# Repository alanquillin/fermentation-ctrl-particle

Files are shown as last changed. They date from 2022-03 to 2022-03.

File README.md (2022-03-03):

# fermentation-controller

A Particle project named fermentation-controller

## Welcome to your project!

Every new Particle project is composed of 3 important elements that you'll see have been created in your project directory for fermentation-controller.

#### ```/src``` folder:  
This is the source folder that contains the firmware files for your project. It should *not* be renamed. 
Anything that is in this folder when you compile your project will be sent to our compile service and compiled into a firmware binary for the Particle device that you have targeted.

If your application contains multiple files, they should all be included in the `src` folder. If your firmware depends on Particle libraries, those dependencies are specified in the `project.properties` file referenced below.

#### ```.ino``` file:
This file is the firmware that will run as the primary application on your Particle device. It contains a `setup()` and `loop()` function, and can be written in Wiring or C/C++. For more information about using the Particle firmware API to create firmware for your Particle device, refer to the [Firmware Reference](https://docs.particle.io/reference/firmware/) section of the Particle documentation.

#### ```project.properties``` file:  
This is the file that specifies the name and version number of the libraries that your project depends on. Dependencies are added automatically to your `project.properties` file when you add a library to a project using the `particle library add` command in the CLI or add a library in the Desktop IDE.

## Adding additional files to your project

#### Projects with multiple sources
If you would like add additional files to your application, they should be added to the `/src` folder. All files in the `/src` folder will be sent to the Particle Cloud to produce a compiled binary.

#### Projects with external libraries
If your project includes a library that has not been registered in the Particle libraries system, you should create a new folder named `/lib/<libraryname>/src` under `/<project dir>` and add the `.h`, `.cpp` & `library.properties` files for your library there. Read the [Firmware Libraries guide](https://docs.particle.io/guide/tools-and-features/libraries/) for more details on how to develop libraries. Note that all contents of the `/lib` folder and subfolders will also be sent to the Cloud for compilation.

## Compiling your project

When you're ready to compile your project, make sure you have the correct Particle device target selected and run `particle compile <platform>` in the CLI or click the Compile button in the Desktop IDE. The following files in your project folder will be sent to the compile service:

- Everything in the `/src` folder, including your `.ino` application file
- The `project.properties` file for your project
- Any libraries stored under `lib/<libraryname>/src`

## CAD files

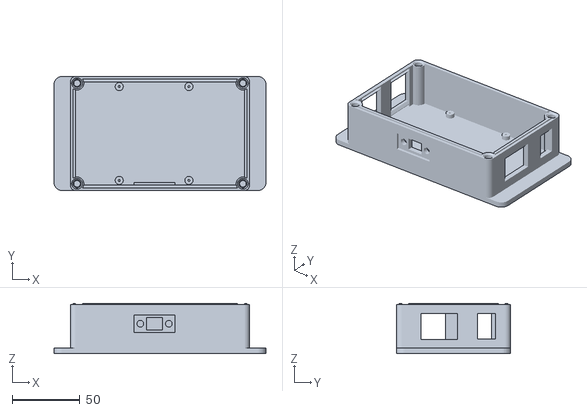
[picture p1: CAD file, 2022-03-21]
drawings/case/case-bottom (Meshed).stl
156.0 x 84.0 x 37.0

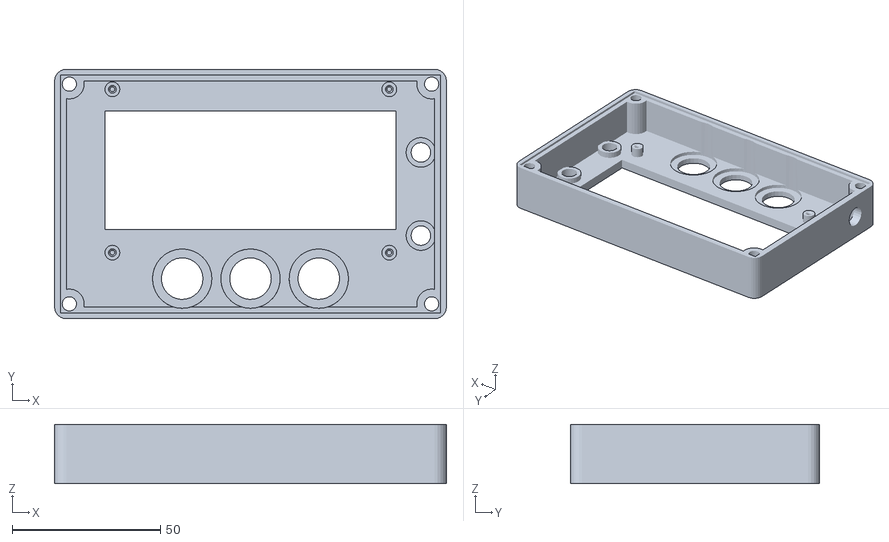
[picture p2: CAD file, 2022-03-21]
drawings/case/case-top (Meshed).stl
132.0 x 84.0 x 20.0

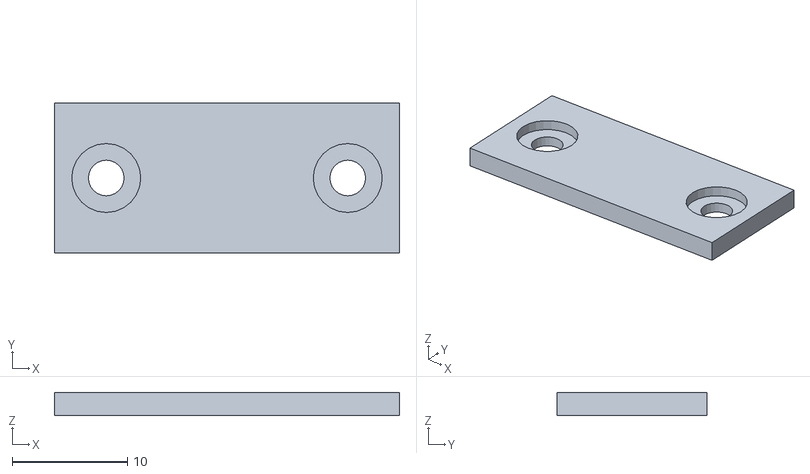
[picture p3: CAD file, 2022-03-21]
drawings/case/case-botton-usb-cover (Meshed).stl
30.0 x 13.0 x 2.00

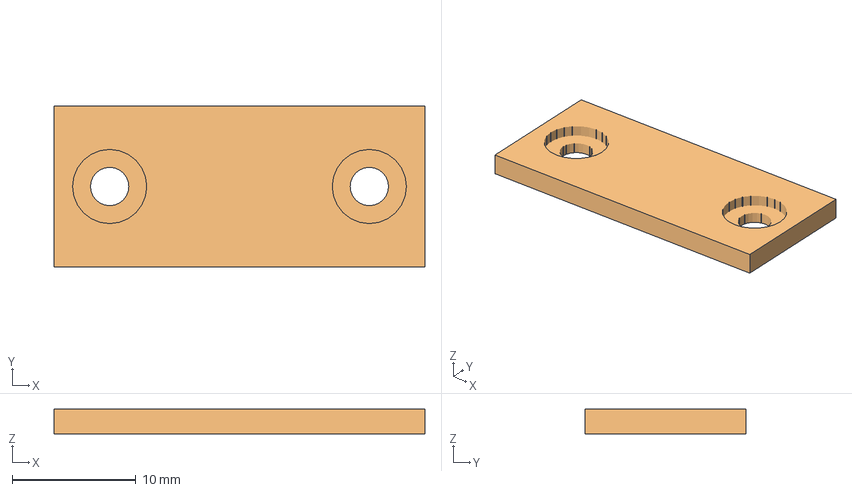
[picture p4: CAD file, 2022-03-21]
drawings/case/case-botton-usb-cover.FCStd
30.0 x 13.0 x 2.00 mm
Cut001 (Meshed)

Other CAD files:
drawings/case/case-bottom.FCStd
drawings/case/case-top.FCStd

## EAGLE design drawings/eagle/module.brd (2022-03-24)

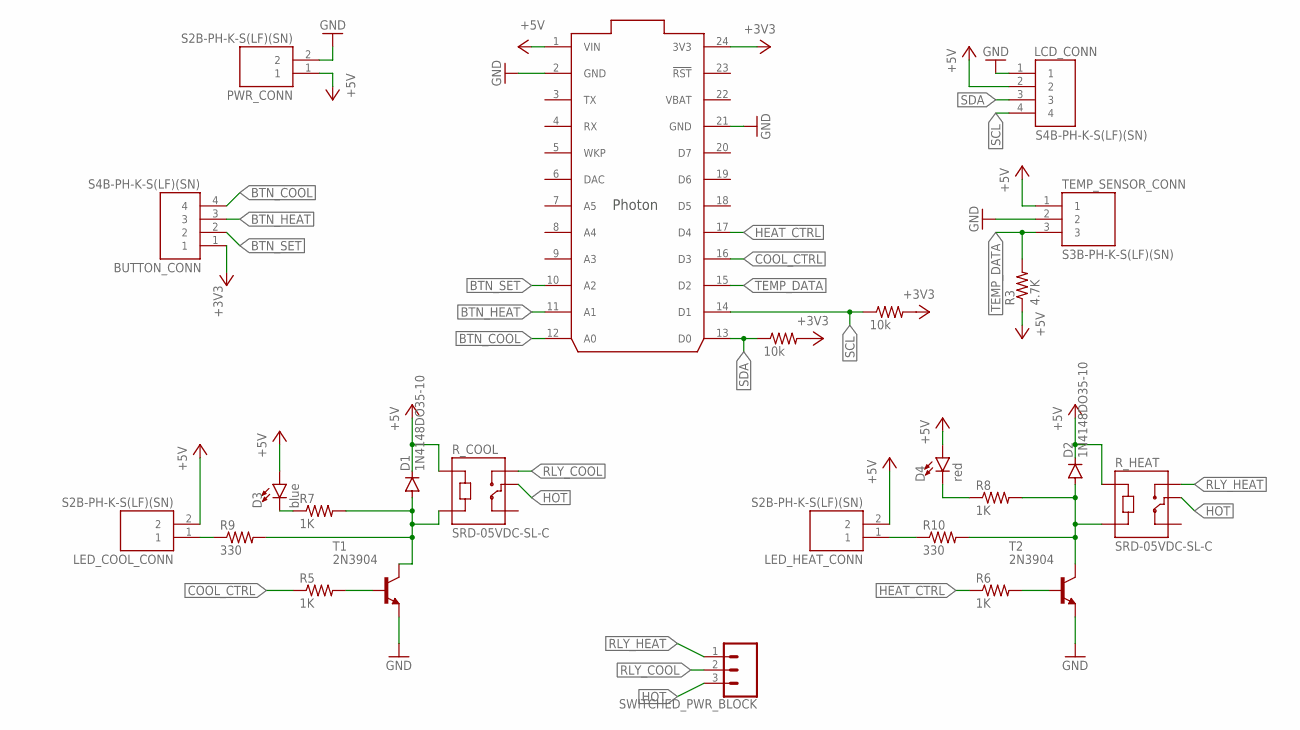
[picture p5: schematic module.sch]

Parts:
BUTTON_CONN: S4B-PH-K-S(LF)(SN); JST_S4B-PH-K-S(LF)(SN); MPN S4B-PH-K-S (LF)(SN)
D1, D2: 1N4148DO35-10; DO35-10; MPN 1N4148 (DO-35)
D3: blue; LED_3MM; MPN TLHB4400
D4: red; LED_3MM; MPN 4300F1LC
LCD_CONN: S4B-PH-K-S(LF)(SN); JST_S4B-PH-K-S(LF)(SN); MPN S4B-PH-K-S (LF)(SN)
LED_COOL_CONN: S2B-PH-K-S(LF)(SN); JST_S2B-PH-K-S(LF)(SN); MPN S2B-PH-K-S (LF)(SN)
LED_HEAT_CONN: S2B-PH-K-S(LF)(SN); JST_S2B-PH-K-S(LF)(SN); MPN S2B-PH-K-S (LF)(SN)
PWR_CONN: S2B-PH-K-S(LF)(SN); JST_S2B-PH-K-S(LF)(SN); MPN S2B-PH-K-S (LF)(SN)
R1, R2: 10k; 0207/10
R3: 4.7K; 0207/10
R5, R6, R7, R8: 1K; 0207/10
R9, R10: 330; 0207/10
R_COOL: SRD-05VDC-SL-C; RELAY_SRD-05VDC-SL-C
R_HEAT: SRD-05VDC-SL-C; RELAY_SRD-05VDC-SL-C
SWITCHED_PWR_BLOCK: CONN_03-SCREW-5MM; SCREWTERMINAL-5MM-3
T1, T2: 2N3904; TO92; MPN 2N3904TF
TEMP_SENSOR_CONN: S3B-PH-K-S(LF)(SN); JST_S3B-PH-K-S(LF)(SN); MPN S3B-PH-K-S (LF)(SN)
U$1: PHOTON_WITH_HEADERS; PHOTON; MPN PHOTONH

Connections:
+3V3: BUTTON_CONN.1, R1.2, R2.2, U$1.24 (3V3)
+5V: D1.C, D2.C, D3.A, D4.A, LCD_CONN.2, LED_COOL_CONN.2, LED_HEAT_CONN.2, PWR_CONN.1, R3.1, R_COOL.A1, R_HEAT.A1, TEMP_SENSOR_CONN.1, U$1.1 (VIN)
BTN_COOL: BUTTON_CONN.4, U$1.12 (A0)
BTN_HEAT: BUTTON_CONN.3, U$1.11 (A1)
BTN_SET: BUTTON_CONN.2, U$1.10 (A2)
COOL_CTRL: R5.1, U$1.16 (D3)
GND: LCD_CONN.1, PWR_CONN.2, T1.3 (E), T2.3 (E), TEMP_SENSOR_CONN.2, U$1.2 (GND), U$1.21 (GND)
HEAT_CTRL: R6.1, U$1.17 (D4)
HOT: R_COOL.COM, R_HEAT.COM, SWITCHED_PWR_BLOCK.3
unnamed: LED_COOL_CONN.1, R9.1
unnamed: LED_HEAT_CONN.1, R10.1
unnamed: D1.A, R7.2, R9.2, R_COOL.A2, T1.1 (C)
unnamed: D3.K (C), R7.1
unnamed: R5.2, T1.2 (B)
unnamed: R6.2, T2.2 (B)
unnamed: D2.A, R8.2, R10.2, R_HEAT.A2, T2.1 (C)
unnamed: D4.K (C), R8.1
RLY_COOL: R_COOL.NO, SWITCHED_PWR_BLOCK.2
RLY_HEAT: R_HEAT.NO, SWITCHED_PWR_BLOCK.1
SCL: LCD_CONN.4, R1.1, U$1.14 (D1)
SDA: LCD_CONN.3, R2.1, U$1.13 (D0)
TEMP_DATA: R3.2, TEMP_SENSOR_CONN.3, U$1.15 (D2)
VBAT: U$1.22 (VBAT)

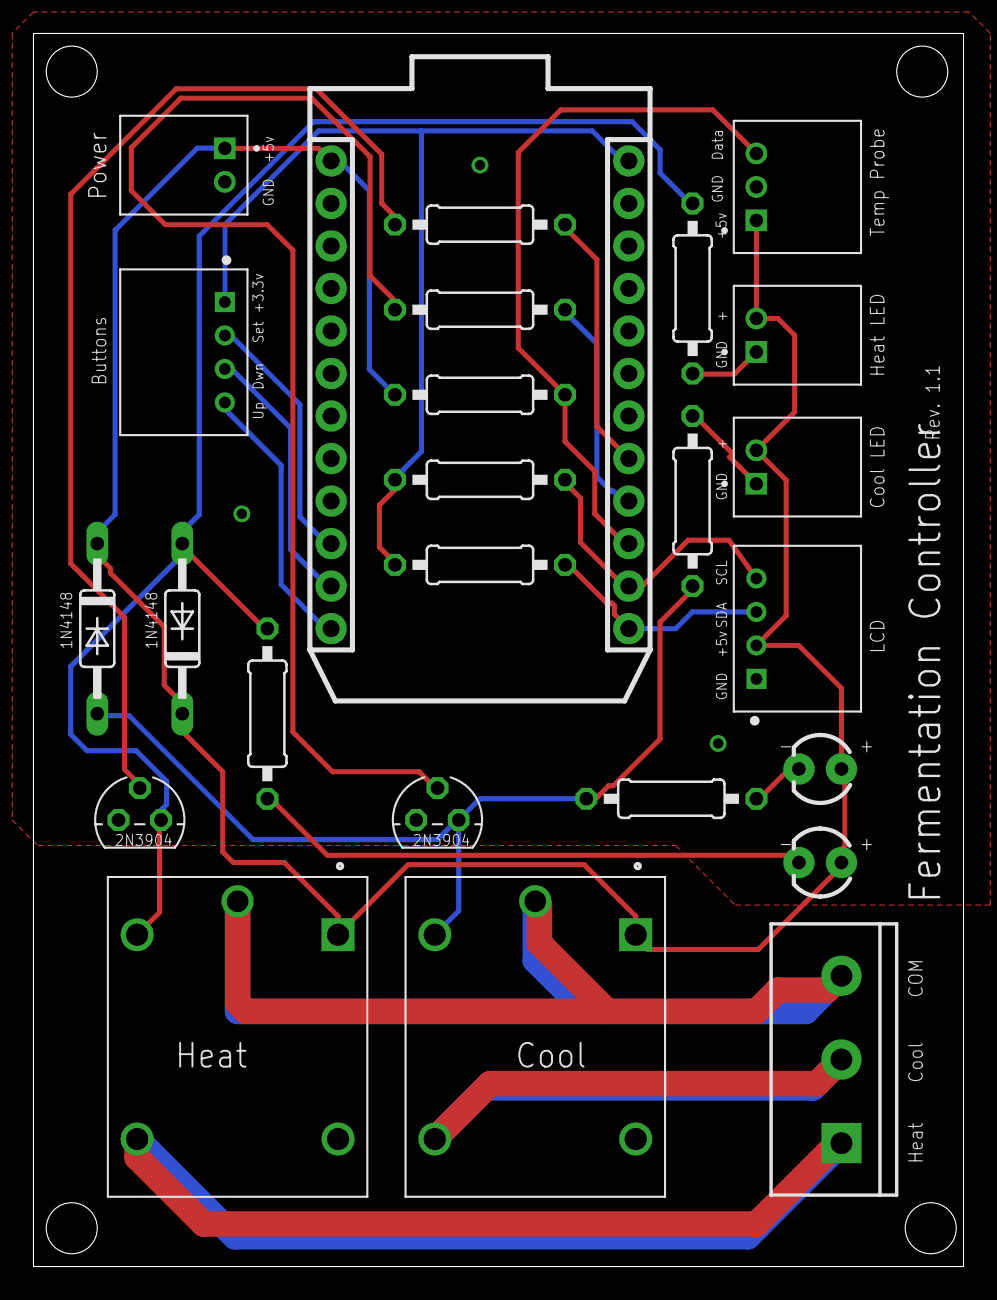
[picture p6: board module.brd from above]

Board: 2 copper layers, 55.5 x 73.7 mm, 25 parts (0 on the bottom side), 22 nets.

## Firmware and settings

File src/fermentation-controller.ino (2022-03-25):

SYSTEM_THREAD(ENABLED);

/*
 * Project fermentation-controller
 * Description:
 * Author: Alan Quillin
 */

#include "constants.h"
#include "diagnostics.h"
#include "service.h"
#include <LiquidCrystal_I2C_Spark.h>
#include <DS18B20.h>
#include <math.h>
#include <CircularBuffer.h>

const LogLevel APP_LOG_LEVEL = LOG_LEVEL_ALL;
SerialLogHandler logHandler(LOG_LEVEL_WARN, { // Logging level for non-application messages
    { "app", APP_LOG_LEVEL }, // Logging level for application messages
    { "app.service", LOG_LEVEL_ALL }
});

//func prototypes
void refreshDisplay(bool clear=false);

// modes
const uint8_t MODE_OFF         = 0;
const uint8_t MODE_COOLING     = 1;
const uint8_t MODE_HEATING     = 2;
const uint8_t MODE_HOLD        = 3;
const uint8_t MODE_DIAGNOSTICS = 10;

// states
const uint8_t STATE_DEFAULT            = 0;
const uint8_t STATE_MENU               = 1;
const uint8_t STATE_MENU_SET_TEMP      = 2;
const uint8_t STATE_MENU_CALIBRATE     = 3;
const uint8_t STATE_MENU_SET_PRECISION = 4;
const uint8_t STATE_MENU_HEAT_DIFF     = 5;
const uint8_t STATE_MENU_COOL_DIFF     = 6;
const uint8_t STATE_MENU_RESET_CONFIG  = 7;

// other constants
const uint8_t MAXRETRY = 4;
const uint16_t LONG_BTN_PRESS_MILS = 2000;
const uint16_t STATS_PUSH_FREQUENCY_MS = 5000;

// dataservice
const String HOST = "<__IP_Address__>";
const uint16_t PORT = 80;

CircularBuffer<device_stats_t,100> stats;

LiquidCrystal_I2C lcd(0x27, 20, 4);
DS18B20 ds18b20(P_DS_DATA, true);

DataService dataService(HOST, PORT);
bool serviceReady = false;
uint32_t serviceFailCnt = 0;
uint32_t lastServiceCheck;
uint32_t lastStatsPush;
String manufacturerId;
String deviceId;
byte mac[6];

struct Config {
  double targetTemp;
  double coolingDifferential;
  double heatingDifferential;
  double tempPrecision;
  double calibrationDiff;
  bool programOn;
};
Config config = {68, 1, 1, .5, 0, true};

double fahrenheit = 0;
double prevFahrenheit = fahrenheit;
double tTargetTemp = config.targetTemp;
double tCoolingDifferential = config.coolingDifferential;
double tHeatingDifferential = config.heatingDifferential;
double tTempPrecision = config.tempPrecision;
double calibrationTemp;
int currentMode = MODE_HOLD;
int displayState = STATE_DEFAULT;
bool refreshLock = false;
uint32_t msLastSample;
long latestMenuActivityTS;

// menu state vars
const String MENU_SET_MODE_OPTION = "<SET MODE>";
const uint8_t MENU_ITEM_SIZE = 9;
const String MENU_ITEMS[MENU_ITEM_SIZE] = {
  "Set Target Temp   ",
  MENU_SET_MODE_OPTION,
  "Calibrate Temp    ",
  "Set Heating Diff  ",
  "Set Cooling Diff  ",
  "Set Temp Precision",
  "Reset Config      ",
  "Run Diagnostics   ",
  "Back              "
};
int menuFirstItemIndex = 0;
int menuItemIndex = 0;

// button state vars
int btnUpState = LOW;
uint32_t btnUpPressStart = 0;
bool btnUpLongPressedHandled = false;
int btnDownState = LOW;
uint32_t btnDownPressStart = 0;
bool btnDownLongPressedHandled = false;
int btnSetState = LOW;
uint32_t btnSetPressStart = 0;
bool btnSetLongPressedHandled = false;

// Timers
Timer tempTimer(2000, getTemp);
Timer refreshDisplayTimer(1000, refreshDisplayWrapper);
Timer setModeTimer(1000, setModeCtl);
Timer menuInactivityTimer(2000, checkMenuInactivity);

Diagnostics diag(lcd, ds18b20, dataService, diagnosticsComplete, diagnosticsCancelled);

// setup() runs once, when the device is first turned on.
void setup() {
  // Put initialization like pinMode and begin functions here.
  Serial.begin(9600);
  
  Log.info("Initializing...");
  Log.trace("Initializing pins...");
  pinMode(P_BTN_UP, INPUT_PULLDOWN);
  pinMode(P_BTN_DOWN, INPUT_PULLDOWN);
  pinMode(P_BTN_SET, INPUT_PULLDOWN);

  pinMode(P_CTRL_COOL, OUTPUT);
  pinMode(P_CTRL_HEAT, OUTPUT);

  for(uint i=0; i < arraySize(EXTRA_GND); i++) {
    pinMode(EXTRA_GND[i], OUTPUT);
    digitalWrite(EXTRA_GND[i], LOW);
  }

  for(uint i=0; i < arraySize(EXTRA_PWR); i++) {
    pinMode(EXTRA_PWR[i], OUTPUT);
    digitalWrite(EXTRA_PWR[i], HIGH);
  }

  Log.trace("Pins initialization done.");

  Log.info("Starting up...");
  lcd.init();
  lcd.backlight();
  lcd.clear();
  lcd.print("Initializing... ");
  
  manufacturerId = System.deviceID();

  Log.trace("Device Manufacturer Id: %s", manufacturerId.c_str());
  WiFi.macAddress(mac);
  Log.trace("Wifi MAC address: %02x:%02x:%02x:%02x:%02x:%02x", mac[0], mac[1], mac[2], mac[3], mac[4], mac[5]);
  Log.trace("Wifi IP address: %s", WiFi.localIP().toString().c_str());

  lcd.setCursor(0,1);
  lcd.print("WiFi... ");
  waitFor(WiFi.ready, 30000);
  lcd.printf("%s", WiFi.ready() ? "connected!" : "timeedout");

  lcd.setCursor(0,2);
  lcd.print("Loading config... ");
  Log.trace("Setting up cloud functions and variables.");
  Particle.function("setTargetTempF", cldSetTargetTemp);
  Particle.function("setMode", cldSetMode);

  Particle.variable("currentTemperature", fahrenheit);
  Particle.variable("tempPrecision", config.tempPrecision);
  Particle.variable("targetTemperature", config.targetTemp);
  Particle.variable("calibrationDifferential", config.calibrationDiff);
  Log.trace("Cloud stuff all set up!");
  
  loadConfig();
  lcd.print("ok");

  lcd.setCursor(0,3);
  lcd.print("Data Svc... ");
  uint8_t pingStatus = ping();
  switch(pingStatus) {
    case 0:
      lcd.print("success!");
      break;
    case 1:
      lcd.print("failed");
      break;
    case 2:
      lcd.print("error");
      break;
  }

  Log.trace("Device Id: %s", deviceId.c_str());
  Log.trace("Target Temp: %.2f", config.targetTemp);
  Log.trace("Target Temp Precision: %.2f", config.tempPrecision);
  Log.trace("Calibration Differential: %.2f", config.calibrationDiff);
  Log.trace("Heating Differential: %.2f", config.heatingDifferential);
  Log.trace("Cooling Differential: %.2f", config.coolingDifferential);
  Log.trace("Program on: %s", config.programOn ? "true" : "false");
  Log.trace("Temp sensor chip type: %x", ds18b20.getChipType());
  Log.trace("Temp sensor chip name: %s", ds18b20.getChipName());

  tempTimer.start();
  refreshDisplayTimer.start();
  setModeTimer.start();

  Log.info("Initialization complete!");
  lcd.setCursor(16,0);
  lcd.print("done");

  delay(2);
  setMode(config.programOn ? MODE_HOLD : MODE_OFF);
  setState(STATE_DEFAULT);
}

// loop() runs over and over again, as quickly as it can execute.
void loop() {
  bool isBtnPresseed = false;
  int _btnUpState = digitalRead(P_BTN_UP);
  uint32_t now = millis();
  if (_btnUpState != btnUpState) {
    if(btnUpState == HIGH) {
      upBtnPressed();
    } else {
      isBtnPresseed = true;
      btnUpLongPressedHandled = false;
      btnUpPressStart = millis();
    }
    btnUpState = _btnUpState;
  } else if (btnUpState == HIGH) {
    isBtnPresseed = true;
    if ((now - btnUpPressStart) >= LONG_BTN_PRESS_MILS && !btnUpLongPressedHandled) {
      upBtnPressedLong();
    }
  }

  int _btnDownState = digitalRead(P_BTN_DOWN);
  if (_btnDownState != btnDownState) {
    if(btnDownState == HIGH) {
      downBtnPressed();
    } else {
      isBtnPresseed = true;
      btnDownLongPressedHandled = false;
      btnDownPressStart = millis();
    }
    btnDownState = _btnDownState;
  } else if (btnDownState == HIGH) {
    isBtnPresseed = true;
    
    if ((now - btnDownPressStart) >= LONG_BTN_PRESS_MILS && !btnDownLongPressedHandled) {
      downBtnPressedLong();
    }
  }

  int _btnSetState = digitalRead(P_BTN_SET);
  if (_btnSetState != btnSetState) {
    if(btnSetState == HIGH) {
      setBtnPressed();
    } else {
      isBtnPresseed = true;
      btnSetLongPressedHandled = false;
      btnSetPressStart = millis();
    }
    btnSetState = _btnSetState;
  } else if (btnSetState == HIGH) {
    isBtnPresseed = true;
    if ((now - btnSetPressStart) >= LONG_BTN_PRESS_MILS && !btnSetLongPressedHandled) {
      setBtnPressedLong();
    }
  }

  if (currentMode == MODE_DIAGNOSTICS) {
    return;
  }

  if (prevFahrenheit != fahrenheit) {
    if(prevFahrenheit != NAN && prevFahrenheit > 0 && prevFahrenheit < 100 && fahrenheit != NAN && fahrenheit > 0 && fahrenheit < 100) {
      float diff = prevFahrenheit - fahrenheit;
      Log.trace("getTemp: _prev: %f, diff: %f", prevFahrenheit, diff);
      if (diff <= -0.02 || diff >= 0.02) {
        Log.trace("getTemp: Temp has changed (after rounding).  Old: %f, New: %f, diff: %f.  Updating database.", prevFahrenheit, fahrenheit, diff);
        prevFahrenheit = fahrenheit;
        stats.push({fahrenheit, Time.now()}); // put stat record to the end of the queue
      }
    } 
  }

  if (!isBtnPresseed && displayState == STATE_DEFAULT) {
    // uint16_t nextCheckFreq = serviceReady ? 10000 : serviceFailCnt > 20 ? 20000 : (serviceFailCnt * 1000);
    // uint32_t elapsed = (now - lastServiceCheck);
    // if (elapsed >= nextCheckFreq) {
    //   Log.trace("%.1f seconds have elapsed since the last service check...", (float(elapsed) / 1000));
    //   Log.info("Pinging service");
    //   ping();
    // }
    // if (serviceReady && (lastStatsPush == 0 || (now - lastStatsPush > STATS_PUSH_FREQUENCY_MS))) {
    //   pushStats();
    // }
  }
}

void setState(int nextState) {
  int _prevDisplayState = displayState;
  
  if (_prevDisplayState == STATE_DEFAULT) {
    refreshDisplayTimer.stop();
  }

  displayState = nextState;
  switch(nextState) {
    case STATE_DEFAULT:
      menuInactivityTimer.stop();
      refreshDisplayTimer.start();
      break;
    case STATE_MENU:
      latestMenuActivityTS = Time.now();
      menuInactivityTimer.start();
      if (_prevDisplayState == STATE_DEFAULT) {
        menuFirstItemIndex = 0;
        menuItemIndex = 0;
      }
      break;
    case STATE_MENU_SET_TEMP:
      tTargetTemp = config.targetTemp;
      break;
    case STATE_MENU_CALIBRATE:
      calibrationTemp = ((isnan(fahrenheit) || fahrenheit <= 0) ? config.targetTemp : fahrenheit) + config.calibrationDiff;
      break;
    case STATE_MENU_HEAT_DIFF:
      tHeatingDifferential = config.heatingDifferential;
      break;
    case STATE_MENU_COOL_DIFF:
      tCoolingDifferential = config.coolingDifferential;
      break;
    case STATE_MENU_SET_PRECISION:
      tTempPrecision = config.tempPrecision;
      break;
  }
  refreshDisplay(true);
}

void upBtnPressed() {
  if (currentMode == MODE_DIAGNOSTICS) {
    diag.upBtnPressed();
    return;
  }
  
  uint32_t now = millis();
  if ((now - btnUpPressStart) >= LONG_BTN_PRESS_MILS) {
    Log.trace("up pressed function ignored since the button is long pressed");
    return;
  }
  Log.trace("Up btn pressed");
  
  if (displayState != STATE_DEFAULT) {
    latestMenuActivityTS = Time.now();
  }

  switch(displayState) {
    case STATE_MENU_SET_TEMP:
      tTargetTemp = tTargetTemp + config.tempPrecision;
      refreshDisplay();
      break;
    case STATE_MENU:
      if (menuItemIndex == 0) {
        menuItemIndex = (MENU_ITEM_SIZE - 1);
        menuFirstItemIndex = menuItemIndex - 2;
      } else {
        menuItemIndex = menuItemIndex - 1;
        if(menuFirstItemIndex > menuItemIndex) {
          menuFirstItemIndex = menuItemIndex;
        }
      }
      refreshDisplay();
      break;
    case STATE_MENU_CALIBRATE:
      calibrationTemp = calibrationTemp + .1;
      refreshDisplay();
      break;
    case STATE_MENU_SET_PRECISION:
      tTempPrecision = tTempPrecision + .1;
      refreshDisplay();
      break;
    case STATE_MENU_HEAT_DIFF:
      tHeatingDifferential = tHeatingDifferential + config.tempPrecision;
      refreshDisplay();
      break;
    case STATE_MENU_COOL_DIFF:
      tCoolingDifferential = tCoolingDifferential + config.tempPrecision;
      refreshDisplay();
      break;
    case STATE_MENU_RESET_CONFIG:
      config = {68, 1, 1, .5, 0, config.programOn};
      saveConfig();
      setState(STATE_MENU);
      break;
  }
}

void upBtnPressedLong() {
  btnUpLongPressedHandled = true;
}

void downBtnPressed() {
  if (currentMode == MODE_DIAGNOSTICS) {
    diag.downBtnPressed();
    return;
  }

  uint32_t now = millis();
  if ((now - btnDownPressStart) >= LONG_BTN_PRESS_MILS) {
    Log.trace("button pressed function ignored since the button is long pressed");
    return;
  }

  Log.trace("Down btn pressed");
  
  if (displayState != STATE_DEFAULT) {
    latestMenuActivityTS = Time.now();
  }

  switch(displayState) {
    case STATE_MENU_SET_TEMP:
      tTargetTemp = tTargetTemp - config.tempPrecision;
      refreshDisplay();
      break;
    case STATE_MENU:
      if (menuItemIndex == (MENU_ITEM_SIZE - 1)) {  
        menuItemIndex = 0;
        menuFirstItemIndex = 0;
      } else {
        menuItemIndex = menuItemIndex + 1;
        if ((menuItemIndex - menuFirstItemIndex) > 2) {
          menuFirstItemIndex = menuItemIndex - 2;
        }
      }
      refreshDisplay();
      break;
    case STATE_MENU_CALIBRATE:
      calibrationTemp = calibrationTemp - .1;
      refreshDisplay();
      break;
    case STATE_MENU_SET_PRECISION:
      if (tTempPrecision > .1) {
        tTempPrecision = tTempPrecision - .1;
        refreshDisplay();
      }
      break;
    case STATE_MENU_HEAT_DIFF:
      if(tHeatingDifferential > 0) {
        tHeatingDifferential = tHeatingDifferential - config.tempPrecision;
        if (tHeatingDifferential < 0) {
          tHeatingDifferential = 0;
        }
        refreshDisplay();
      }
      break;
    case STATE_MENU_COOL_DIFF:
      if(tCoolingDifferential > 0) {
        tCoolingDifferential = tCoolingDifferential - config.tempPrecision;
        if (tCoolingDifferential < 0) {
          tCoolingDifferential = 0;
        }
        refreshDisplay();
      }
      break;
    case STATE_MENU_RESET_CONFIG:
      setState(STATE_MENU);
      break;
  }
}

void downBtnPressedLong() {
  btnDownLongPressedHandled = true;
}

void setBtnPressed() {
  uint32_t now = millis();
  if ((now - btnSetPressStart) >= LONG_BTN_PRESS_MILS) {
    return;
  }

  if (currentMode == MODE_DIAGNOSTICS) {
    diag.setBtnPressed();
    return;
  }

  if (displayState != STATE_DEFAULT) {
    latestMenuActivityTS = Time.now();
  }

  switch(displayState) {
    case STATE_DEFAULT:
      setState(STATE_MENU_SET_TEMP);
      break;
    case STATE_MENU:
      switch(menuItemIndex) {
        case 0:
          setState(STATE_MENU_SET_TEMP);
          break;
        case 1:
          setMode(currentMode == MODE_OFF ? MODE_HOLD : MODE_OFF);
          config.programOn = currentMode != MODE_OFF;
          saveConfig();
          // TODO: Update data service
          // deviceService.updateProgramState(deviceId, config.programOn);
          setState(STATE_DEFAULT);
          break;
        case 2:
          calibrationTemp = fahrenheit;
          setState(STATE_MENU_CALIBRATE);
          break;
        case 3:
          setState(STATE_MENU_HEAT_DIFF);
          break;
        case 4:
          setState(STATE_MENU_COOL_DIFF);
          break;
        case 5:
          setState(STATE_MENU_SET_PRECISION);
          break;
        case 6:
          setState(STATE_MENU_RESET_CONFIG);
          break;
        case 7:
          setMode(MODE_DIAGNOSTICS);
          diag.run();
          break;
        case 8:
          setState(STATE_DEFAULT);
          break;
      }
      break;
    case STATE_MENU_SET_TEMP:
      config.targetTemp = tTargetTemp;
      saveConfig();
      // TODO: Update data service
      // deviceService.updateTargetTemp(deviceId, config.targetTemp);
      setState(STATE_MENU);
      break;
    case STATE_MENU_CALIBRATE:
      config.calibrationDiff = calibrationTemp - fahrenheit;
      saveConfig();
      // TODO: Update data service
      // deviceService.updateCalibrationDiff(deviceId, config.calibrationDiff);
      setState(STATE_MENU);
      break;
    case STATE_MENU_HEAT_DIFF:
      config.heatingDifferential = tHeatingDifferential;
      saveConfig();
      // TODO: Update data service
      // deviceService.updateHeatingDifferential(deviceId, config.heatingDifferential);
      setState(STATE_MENU);
      break;
    case STATE_MENU_COOL_DIFF:
      config.coolingDifferential = tCoolingDifferential;
      saveConfig();
      // TODO: Update data service
      // deviceService.updateCoolingDifferential(deviceId, config.coolingDifferential);
      setState(STATE_MENU);
      break;
    case STATE_MENU_SET_PRECISION:
      config.tempPrecision = tTempPrecision;
      saveConfig();
      // TODO: Update data service
      // deviceService.updatePrecision(deviceId, config.tempPrecision);
      setState(STATE_MENU);
      break;
  }
}

void setBtnPressedLong() {
  btnSetLongPressedHandled = true;

  if (currentMode == MODE_DIAGNOSTICS) {
    Log.trace("In diag mode, Set buttons long held... cancelling diagnostics.");
    diagnosticsCancelled();
    return;
  }

  if (displayState != STATE_DEFAULT) {
    latestMenuActivityTS = Time.now();
  }

  switch(displayState) {
    case STATE_DEFAULT:
      setState(STATE_MENU);
      break;
    case STATE_MENU:
      setState(STATE_DEFAULT);
      break;
    case STATE_MENU_CALIBRATE:
    case STATE_MENU_SET_PRECISION:
    case STATE_MENU_SET_TEMP:
    case STATE_MENU_HEAT_DIFF:
    case STATE_MENU_COOL_DIFF:
      setState(STATE_MENU);
      break;
  }
  
}

void setMode(uint8_t mode) {
  //int _previousMode = currentMode;
  currentMode = mode;
}

void setModeCtl() {
  if (currentMode == MODE_DIAGNOSTICS) {
    return;
  }
  //int _previousMode = currentMode;

  if(currentMode != MODE_OFF) {
    if(fahrenheit > 0 && fahrenheit != NAN) {
      switch(currentMode) {
        case MODE_COOLING:
          if(fahrenheit <= config.targetTemp) {
            setMode(MODE_HOLD);
          }
          break;
        case MODE_HEATING:
          if(fahrenheit >= config.targetTemp) {
            setMode(MODE_HOLD);
          }
          break;
        case MODE_HOLD:
          setMode(fahrenheit > (config.targetTemp + config.coolingDifferential) ?  MODE_COOLING : fahrenheit < (config.targetTemp - config.heatingDifferential) ? MODE_HEATING : MODE_HOLD);
          break;
      }
    } else {
      setMode(MODE_HOLD);
      //Log.trace("Temp sample is %f, setting to Hold as something is weird...", fahrenheit);
    }
  }

  switch(currentMode) {
    case MODE_COOLING:
      digitalWrite(P_CTRL_COOL, HIGH);
      digitalWrite(P_CTRL_HEAT, LOW);
      break;
    case MODE_HEATING:
      digitalWrite(P_CTRL_COOL, LOW);
      digitalWrite(P_CTRL_HEAT, MODE_HEATING);
      break;
    case MODE_HOLD:
      digitalWrite(P_CTRL_COOL, LOW);
      digitalWrite(P_CTRL_HEAT, LOW);
      break;
    case MODE_OFF:
      digitalWrite(P_CTRL_COOL, LOW);
      digitalWrite(P_CTRL_HEAT, LOW);
      break;
  }
}

void refreshDisplayWrapper() {
  if (currentMode == MODE_DIAGNOSTICS) {
    return;
  }

  refreshDisplay(false);
}
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

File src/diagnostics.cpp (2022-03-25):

#include "diagnostics.h"
#include "constants.h"
#include "service.h"
#include <LiquidCrystal_I2C_Spark.h>
#include <DS18B20.h>

/**
* Constructor.
*/
Diagnostics::Diagnostics(LiquidCrystal_I2C& _lcd, DS18B20& _ds18b20, DataService& _dataService, void (*_onComplete)(), void (*_onCancel)())
    : lcd{_lcd}, ds18b20{_ds18b20}, dataService{_dataService}, logger("app.diagnostics")
{
    onComplete = _onComplete;
    onCancel = _onCancel;

    lcd.init();
    lcd.backlight();
    lcd.clear();
}

void Diagnostics::run() {
    logger.trace("Starting diagnostics.");

    errCnt = 0;
    wifiTestStatus = "pending...  ";
    wifiTestComplete = false;
    serviceTestStatus = "pending...  ";
    serviceTestComplete = false;
    tempProbeDriver = "";
    tempProbeTemp = 0;
    tempProbeTestComplete = false;

    digitalWrite(P_CTRL_COOL, LOW);
    digitalWrite(P_CTRL_HEAT, LOW);
    
    clearScreen();
    setState(INIT);
}

void Diagnostics::setState(States _state) {
    state = _state;

    refreshScreen();

    switch(state) {
        case WIFI:
            testWifi();
            break;
        case SERVICE:
            testService();
            break;
        case TEMP_PROBE:
            testTempProbe();
            break;
        case HEAT_OUTLET:
            testHeatOutlet();
            break;
        case COOL_OUTLET:
            testCoolOutlet();
            break;
    }
}

void Diagnostics::upBtnPressed(){
    switch(state) {
        case INIT:
            setState(WIFI);
            break;
        case WIFI:
            if(wifiTestComplete) {
                setState(SERVICE);
            }
            break;
        case SERVICE:
            if(serviceTestComplete) {
                setState(TEMP_PROBE);
            }
            break;
        case TEMP_PROBE:
            if(tempProbeTestComplete) {
                setState(UP_BTN);
            }
            break;
        case UP_BTN:
            lcd.setCursor(0,3);
            lcd.print("Passed!             ");
            delay(500);
            setState(DOWN_BTN);
            break;
        case HEAT_OUTLET:
            digitalWrite(P_CTRL_HEAT, LOW);
            setState(COOL_OUTLET);
            break;
        case COOL_OUTLET:
            digitalWrite(P_CTRL_COOL, LOW);
            setState(RESULTS);
            break;
        case RESULTS:
            onComplete();
            break;
    }
}

void Diagnostics::downBtnPressed() {
    switch(state) {
        case INIT:
            onCancel();
            break;
        case WIFI:
            if(wifiTestComplete) {
                onCancel();
            }
            break;
        case SERVICE:
            if(serviceTestComplete) {
                onCancel();
            }
            break;
        case TEMP_PROBE:
            if(tempProbeTestComplete) {
                onCancel();
            }
            break;
        case DOWN_BTN:
            lcd.setCursor(0,3);
            lcd.print("Passed!             ");
            delay(500);
            setState(SET_BTN);
            break;
        case HEAT_OUTLET:
            digitalWrite(P_CTRL_HEAT, LOW);
            errCnt = errCnt + 1;
            setState(COOL_OUTLET);
        case COOL_OUTLET:
            digitalWrite(P_CTRL_COOL, LOW);
            errCnt = errCnt + 1;
            setState(RESULTS);
    }
}

void Diagnostics::setBtnPressed() {
    switch(state) {
        case SET_BTN:
            lcd.setCursor(0,3);
            lcd.print("Passed!             ");
            delay(500);
            setState(HEAT_OUTLET);
            break;
    }
}

void Diagnostics::clearScreen(){
    for(uint i=0; i < 4; i++) {
        lcd.setCursor(0, i);
        lcd.print(EMPTY_ROW);
    };
}

void Diagnostics::clearLines(uint8_t *lines, uint8_t size){
    for(uint i=0; i < size; i++) {
        lcd.setCursor(0, lines[i]);
        lcd.print(EMPTY_ROW);
    };
}
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

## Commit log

2022-03-03 initial commit - big bang
    [module.brd, module.sch]
2022-03-21 Updated to use the log library and split the heat and cool differencial
2022-03-21 Finished rev1 of the circuit board and moved to a drawings directory
    [module.brd, module.sch]
2022-03-21 Added 3d model for the case
    [case-bottom (Meshed).stl, case-bottom.FCStd, case-botton-usb-cover (Meshed).stl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]
2022-03-22 Added new “Reset Config” menu option and functionality
    [fermentation-controller.ino]
2022-03-24 Fixed incorrect wiring for the temp probe
    [module.brd, module.sch]
2022-03-25 Updated loading screen and added set button on default display to allow setting target temp
2022-03-25 shortened the diagnostics button press delay
    [diagnostics.cpp]

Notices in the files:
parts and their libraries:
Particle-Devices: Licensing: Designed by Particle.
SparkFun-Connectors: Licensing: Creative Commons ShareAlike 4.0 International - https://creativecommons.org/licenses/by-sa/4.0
